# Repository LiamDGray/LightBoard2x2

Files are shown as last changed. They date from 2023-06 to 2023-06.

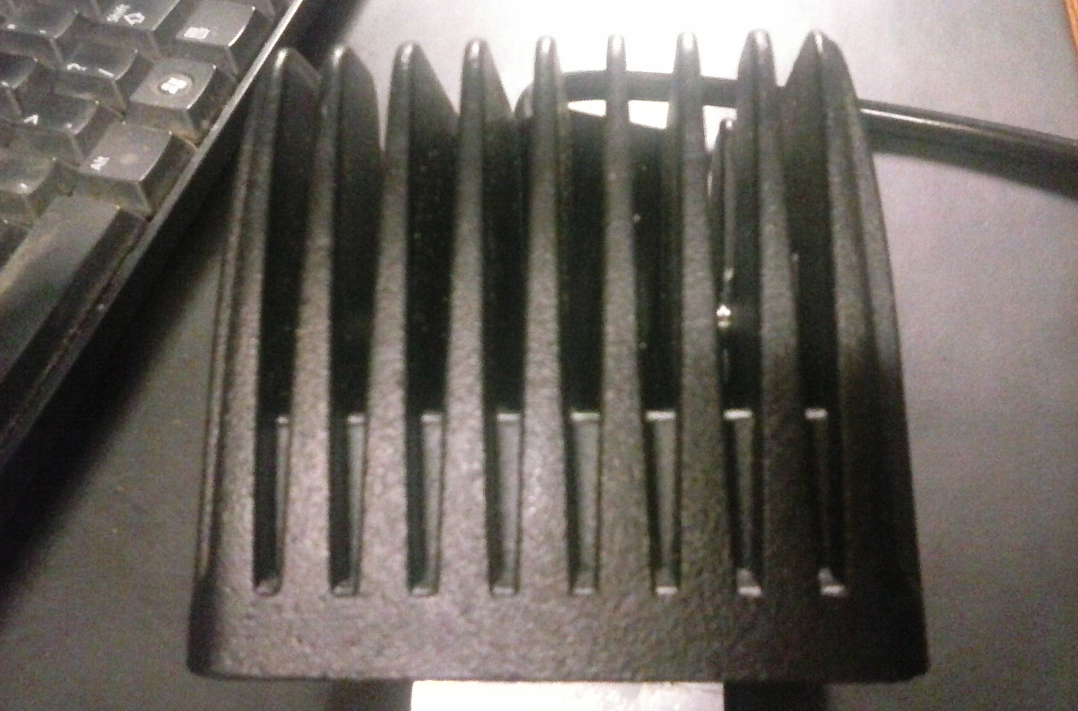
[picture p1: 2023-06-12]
Photos of Chinese product/Chinese 2x2 housing top.jpg

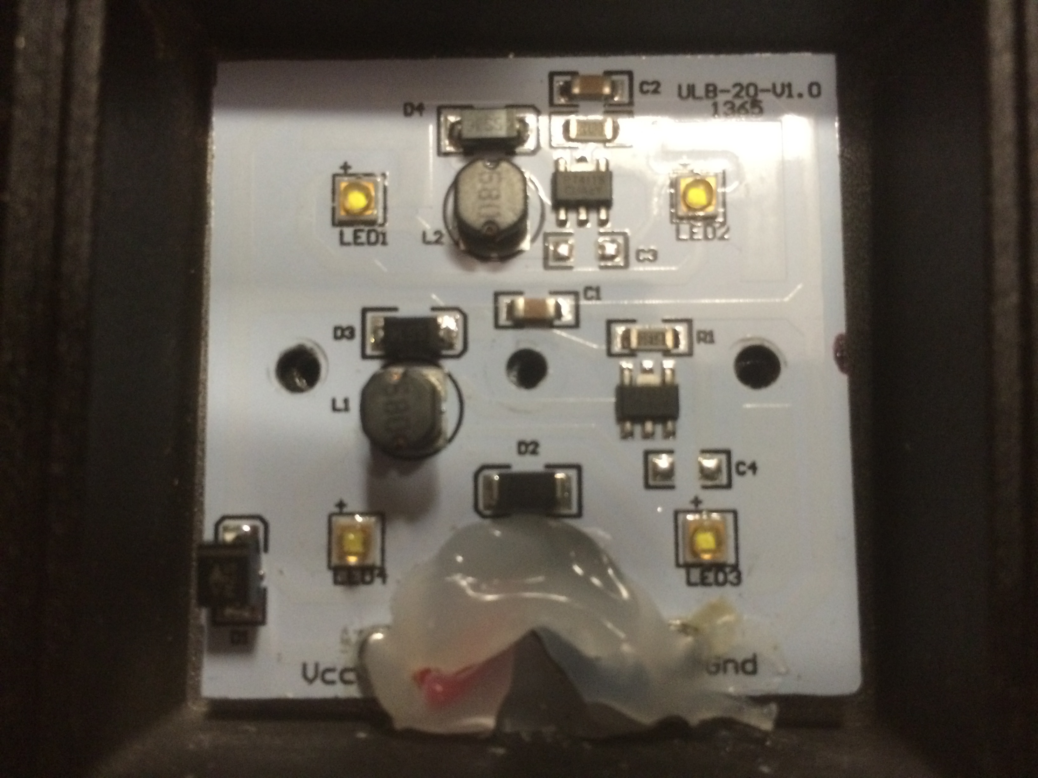
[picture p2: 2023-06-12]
Photos of Chinese product/Chinese 2x2_ board.JPG

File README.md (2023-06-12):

High-power 2x2 LED board based on PicoBuck LED Driver
===================

### Repository Contents
-------------------
- Design notes.docx
- Eagle CAD source files/
- LICENSE.md
- Light bar schematic.pdf
- Mechanical_drawing_of_board_for_subs.pdf
- Photos of Chinese product/
- Quotes/
- README.md (this file)
- Requirements traceability matrix.xlsx
- Simulations _ spreadsheets/
- Specifications for board fab _ assembly/
- Test results/

### License Information
-------------------
- The hardware is released under [Creative Commons Attribution-ShareAlike 3.0 Unported (CC BY-SA 3.0)](http://creativecommons.org/licenses/by-sa/3.0/).  Please feel free to do anything you want with it; just keep this license attached.

### Additional Information
----------------------
- My starting point was the [SparkFun PicoBuck](https://github.com/sparkfun/PicoBuck) LED driver, which was a collaboration with Ethan Zonca and also licensed under CC BY-SA 3.0.
- I used Eagle CAD 7.2.0 (a version current in early 2015).
- I added thermal foldback and dimming.
- I designed this board in 2015 at the request of [Traxda, LLC](https://www.traxda.com/) in Tucson, Arizona, USA. Traxda was kind enough to accept the work product under this same license (CC BY-SA 3.0).
- This was my first LED board, my first constant-current power supply, my first use of thermal foldback, my first dimming LED driver, and my first PCB. Back in 2015, I fabricated multiple iterations of the board and did basic functional testing, but I was unable to find a subcontractor with the equipment to test for electromagnetic compatibility (EMC) or otherwise review my design. My client, Traxda, opted not to have me finish, and I moved on to other things.
- In 2023, I am thinking of adapting the design for something related to LiFi and OpenVLC.
- If you have any suggestions, please open an issue or, better yet, make a pull request!
- You're welcome to sponsor my work through [Github Sponsors](https://github.com/sponsors/LiamDGray/).

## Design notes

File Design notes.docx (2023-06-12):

# Design Notes for v.1

(a 2x2” board to replace the Chinese board in a 3x3” light)

# Component selection

We have designed the present board to meet the first requirement: a drop-in warranty replacement board for the Chinese lights currently being advertised as having “four 5W LEDs.” However, it is unlikely that the LEDs in the Chinese board really are 5W LEDs. They seem to be 3W LEDs, for a few reasons:

5W LEDs currently available through US distributors (1) are quite expensive (starting at $4.91 apiece at quantity 2500 at DigiKey) and (2) require higher voltages (around 6 or 7 volts) than the 2.9 volts apiece of the 3W LEDs used in the present design. (3) Known 5W LEDs also are larger (e.g. 5.7mm diameter) than the LEDs in the Chinese board (2mm diameter) and would not fit within the apertures of the reflectors designed for this board.

Philips Luxeon Rebel LEDs were selected for their small size, high lumens per watt, low price, and plentiful availability in quantities sufficient for production runs of 1000 boards. In fact, all components were chosen for their availability; any components with limited distributor inventory were replaced with more-plentiful substitutes. (For production quantity, DigiKey, Mouser, Avnet, and CM’s preferred vendors should be checked for best prices.)

Automotive compliant (AEQ rated) components were selected whenever possible. And, as a voltage reference, the 5.6V Zener diode was selected for its relatively good temperature stability versus Zener diodes of higher and lower voltages.

References:

http://www.digikey.com/product-search/en/optoelectronics/led-lighting-white/525606?stock=1

http://www.aecouncil.com/AECDocuments.html

# Schematic

The present design, v.1, is a derivative of PicoBuck, which was designed by Ethan Zonca. Specifically, it follows two of PicoBuck’s three parallel buck driver circuits.

Each of the two parallel buck drivers drives a series of two 3-watt (2.9 volt) LEDs with a nominal 680mA current. This level of current approximates the current at which the LEDs’ manufacturer measured their performance. Optionally, switching the values of resistors R1A and R1B to 0.10 Ohm would result in the LEDs being driven with current of up to 972mA (43% greater) and emitting brighter light, subject to thermal foldback. Since the thermal foldback feature (see below) limits average current in order to keep temperature below 85 degrees Celsius, the higher-valued resistors may or may not increase brightness.

In addition, a subcircuit on the input improves electromagnetic compatibility in the automotive environment.

The schematic was developed in Cadsoft Eagle. It (with extension .sch) and the board layout (with extension .brd) were last edited with version 7.2 (freeware edition) and are stored in the folder “Eagle CAD source files.”

# Simulation

Simulation was done in Zetex Circuit Simulator, which is available free of charge as a download from Diodes Inc, maker of the driver chip used in this design. The simulation file is stored as “v.1.sxsch.” Dimmer circuit calculations were done in a Google Sheets spreadsheet called “Dimmer circuit calculations.” Both are stored in the folder “Simulations and Spreadsheets” in the project’s Google Drive folder.

# Layout

The printed circuit board (PCB) was laid out almost entirely in large planes (broad rectangular areas), rather than in thin traces, to minimize inductance and interference with nearby electronic devices. To minimize inductive loops:

- C1 was placed very close to the driver’s Vin pin
- R1 was placed very close to the driver’s pins Vin and SET
- D1’s anode and the inductor were placed very close to the driver’s SW pin

The broad planes also prove durable, resist tearing, during rework. However, the pads are without thermal relief. (For this reason, oven reflow is recommended.)

The board has holes in the same pattern as in the original board, but the center hole has been enlarged (as per the drawing provided by Company) to match the size of the other two.

# Thermal considerations

To dissipate heat efficiently, to maximize the life of LEDs and other components on the board, the Philips Luxeon Rebel datasheet was followed. This specified the number, size, and placement of plated through-holes (copper-lined holes connecting board’s top and bottom layers), as thermal vias, around each LED. These thermal vias conduct heat into the ground plane, the bottom layer of the board. This is bare metal (not covered by an insulating solder mask) and interfaces via a thermally conductive pad (made from Bergquist’s Sil-Pad K-4 material) to the heatsink/case of the light fixture. The datasheet also specified 1-ounce copper and 0.8mm FR-4 as the board material. This material, half the most common PCB thickness, offers less thermal resistance than the typical 1.6mm PCB. This board thickness, and the 12 mil minimum drill size, are not available at all board houses (PCB fabricators).

The board’s copper is coated in ENIG (electroless nickel immersion gold) to maximize thermal conductivity.

The thermal pad is optional, but in an automotive environment it is recommended. It is intended to prevent the gradual wearing off of the thin gold coating (ENIG) of the board’s bottom layer, due to friction against the heatsink/housing.

# Dimming

Dimming is via an external potentiometer, which shall be connected via a twisted wire pair exiting the assembly via the same cable that includes the power and ground pair. At full counter-clockwise rotation, the potentiometer’s resistance should be near zero and should result in lights being very dim or turning off. Turned full clockwise, its resistance should be around 500kOhms (+/- 20%; each of the two samples encountered during prototyping measured 400kOhms) and should result in the lights reaching maximum brightness.

The mounting of the external potentiometer is TBD but could include mounting through a hole in an existing panel of the vehicle or in a small enclosure which mounts flush to some surface of the vehicle’s cab.

# Thermal Foldback

Additional dimming to prevent overheating of the LEDs is achieved through the use of a negative temperature coefficient thermistor placed near the bottom right LED. As LEDs heat up slightly, so will this thermistor, whose resistance decreases, which reduces the voltage at the drivers’ CTRL pins, which reduces the current through the LEDs, which cools them slightly. The circuit was calibrated to let the thermistor stay just shy of 85 degrees Celsius, the temperature at which the LEDs’ performance was measured and specified.

# EMC: electromagnetic compatibility

The board was designed to reduce electromagnetic emissions (make it act less like a radio transmitter) and to resist damage from it and other components being connected or disconnected, or from transient spikes in voltage. Toward this end, the following references were consulted and synthesized:

“AL8805 MR16 EMC guide” downloaded from:

http://www.digikey.com/videos/en/v/AL8805-MR16-EMC-guide/2195801950001

“AN57: Automotive EMC considerations for switching regulator LED lighting applications using ZXLD1362” downloaded from:

http://www.diodes.com/_files/products_appnote_pdfs/zetex/an57.pdf

“AL8805 Calculator” downloaded from:

http://www.diodes.com/calculators.html

“Design an L-C Low pass or High pass Filter (V 1.1 May 18, 2008)” at:

http://www.wa4dsy.net/filter/hp_lp_filter.html

AN57 provided an example for the input subcircuit, which includes a load dump and battery reverse protection and an input “Pi” filter tuned to prevent the switching frequency of the drivers from being injected into the power supply. The switching frequency was calculated by the AL8805 Calculator, an Excel spreadsheet provided by Diodes Inc.. Together, these circuit elements protect the board and surrounding electronics from conducted electromagnetic emissions and from other events that can occur the automotive environment and could damage circuits.

# PCB fabrication

Given the particularly small minimum drill size and the 0.8mm FR-4 material, not all board houses can produce this design. To find a suitable US-based board house, the document “Light bar fab notes.pdf” should be sent with any request for quotation. This will enable the board house to determine whether they can meet the requirements. (Note: The Contract Manufacturer [CM] retained to assemble the board could select the board house to produce the PCBs.)

# PCB assembly

Assembly considerations include vibration resistance, European regulatory compliance (TBD) and cable (TBD).

The inductor L1 should be epoxied to the board for vibration resistance. So too, whoever attaches the cable should epoxy the ends of each wire near their solder joints to the board.

The board should be assembled with lead-free solder if (TBD, depending on the cost of this option) Company decides product is to meet European requirements after January 1, 2016. After that date, the European “ELV” (End of Life Vehicle) exemption 8a, permitting leaded solder, may expire.

If lead-free solder is used, the board should be conformally coated with 2-mil “Arathane” (urethane) to prevent the growth of tin “whiskers.” This has been reported to work for 11 years, at least.

An approximately one-foot length of cable should be cut, stripped, tinned, and soldered to (four pads on) each board, either by the board assembler or in-house (TBD, depending on cost). This cable is specified in the document “Cable Specification” in the folder “Specifications for board fab and assembly.”

# Mechanical assembly

This shall be done in-house. As in the Chinese original,

1. A water resistant grommet providing strain relief should fit snugly around the cable where it exits the assembly.
2. Silicone should be used to fill and seal the hole around the cable on the board side.

# Future design for increased brightness

One engineer described the present housing and heatsink as “overbuilt” for the circuit board and LEDs it contains, and given summer warehouse temperature measurements, likely the housing really can dissipate 20W or more.

For a future design with 5W (or greater) LEDs, to create the higher voltage required, one would replace the two “buck” drivers with a single “buck-boost” driver. A buck-boost design can drive a series of LEDs whose total voltage exceeds that of the input power supply. Thus from, for example, a 12V supply, even with 10% loss, resulting in 10.8V available, one could drive LED series totalling 12V, 20V, or even more.

This might require substituting the reflector assembly also, for reflectors with a larger aperture. A hack during prototyping might be to drill out the apertures in the current reflectors.

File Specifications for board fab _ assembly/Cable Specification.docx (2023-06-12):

# Cable Specification

# Requirements

1. Cable's total length (end to end) is about 12 inches (tolerance +/- 0.5 inch)
2. 2. A flexible rubber or plastic grommet for strain relief and water resistance shall fit snugly around cable and shall fit into a hole whose diameter is 10.4mm +/- 0.1mm.
3. Cable, preferably shielded, shall contain two twisted pairs of #18 to #22 stranded copper wire.
4. Cable's jacket shall be stripped 1 inch (+/- 0.25” ) back from each end of cable.
5. Each of the four wires' insulation shall be stripped 0.25” (+/- 0.125”) back from each end and shall be tinned at each end.
6. One pair of wires shall be soldered to VCC and GND (red and black, respectively, if available).
7. One end of the other pair (for example, white and green) shall be soldered to DIM1 and DIM2. This pair’s other end shall be soldered to the potentiometer’s wiper (terminal 2, center terminal) and to the left terminal, such that a clockwise turn increases resistance between these two connected terminals. (The two wires could be reversed with no consequence; order is not important. The potentiometer is used as a variable resistor, with its third terminal floating.)
8. The wires shall be epoxied to the board near the solder joints.
9. Preferably the jacket is UV-resistant.

# Examples

One or more of the following cable stock, sold by the foot, may meet the requirements, if a suitable grommet can be found:

- 2 twisted pair 20 AWG shielded, $1.88 per foot: http://www.digikey.com/product-search/en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
- 3 pair 22 AWG shielded -- could combine two pair for power? $2.59 per foot: http://www.digikey.com/product-detail/en/25483%20BK005/25483%20BK005-ND/5120450
- 2 twisted pair 22 AWG shielded, $0.83 to $0.43 per foot: http://www.altex.com/Belden-22AWG-2-Pair-Shielded-Twisted-Pair-Cable-8723-BEL-P140284.aspx

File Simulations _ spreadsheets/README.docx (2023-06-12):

README

Simulations in this folder are for Zetex Circuit Simulator, which can be

downloaded from Diodes Inc at:

http://www.diodes.com/simulators.html

As of April 2, 2015, the last version run was version 5.40b, on Windows 8.

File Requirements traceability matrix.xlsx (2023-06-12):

Category | Requirement | Notes | BOM (https://drive.google.com/#folders/0B2ThqQRnzscgajMyOXN3WFJqMWc) | Schematic | Simulation | Layout | Prototype
Luminous flux or luminous power | At low temperatures (max intensity), within 10% of that of the model board (TBD, probably about 220 lumens per LED emitter) | TBD (will specify after we measure the model using an integrating sphere) | Luxeon Rebel ES emitters | LED1A,LED2A,LED1B,LED2B
Emitters' viewing angle | TBD | TBD (will specify after we measure the model's emitters) http://www.barco.com/~/media/Downloads/White%20papers/2014/WhitePaper%20Viewing%20Angle_final%20pdf.pdf and http://www.candlepowerforums.com/vb/showthread.php
Power consumption (Watts) | Chinese board draws 13.2W +/- 1W | The model board draws 1.1A at 12V (about 1.1A per 6V parallel branch) | parts sized to carry 2A or 1A current, plus tolerance | If R1A and R1B are set to permit 680mA current through each 5.8V series of LEDs, the board should draw around 7.9W. At 12V that would be about 0.66A. If current is 972mA, the board should draw up to (0.66A * 972 / 680), or 0.94A, subject to thermal foldback.
Thermal tolerance | At least 50C ambient (see notes, right) or preferably 70C | At least 50C, though parts are rated at or below 85 degC. Thermal foldback circuit calibrated to keep below 85 degC. |  | RNTC1, R4 | N/A
 | Meet specs by LED emitter manufacturer (e.g. Philips) | www.cree.com/xlamp_app_notes/thermal_management and www.cree.com/xlamp_app_notes/pcb_thermal Use Aluminum board or 0.8mm FR-4, which is much easer to find in 2 layers and will suffice due to thermal foldback. In summer, model board only reached 115 degF in warehouse in Tucson. |  | see net "TH" | N/A | Thermal vias around each emitter
 |  | In summer, model board only reached 115 degF (about 46 degF) in warehouse in Tucson.
Color temperature ("cool white" vs "warm white") | About 5000K | Match model board's emitters (specific color temp TBD)
Electro-magnetic compatibility (EMC) | Emissions not worse than emission spectrum from "Diodes [Zetex] Circuit Simulator" (or other free SPICE implementation) transient simulation of model circuit, to be posted shortly. | Probably not crucial for aftermarket automotive accessories. Stretch goal could be to meet specs below by following principles as in http://diodes.com/_files/products_appnote_pdfs/zetex/an57.pdf and http://diodes.com/_files/simulator/AN57_1362_emc_compliant_at_350mA.sxsch |  | C5,L2,C1
 |  | CISPR-25: Conducted and radiated emissions (Europe and Worldwide standards)
 |  | ISO11452: Radiated immunity (North America and Worldwide standards)
 |  | 95/54/EC: Radiated emissions (European standards)
 |  | May prefer hysteretic controller (varying frequency) for EMI reduction (e.g. the PT4115 in the model board)
 |  | May use Pi filter (C,L,C) | C5,L2,C1 | C5,L2,C1
 |  | Use twisted pair for power/ground and dim
Mechanical | Board shall fit 47mm square contour (X,Y = 47mm x 47mm) | See photos in folder https://drive.google.com/folderview?id=0B2ThqQRnzscgajMyOXN3WFJqMWc&usp=drive_web
 | Shall have holes placed and sized to fit the two board-mounting screws and one (central) reflector-mounting screw (measurements below)
 | Emitter shall fit inside 5.2mm diameter aperture at reflector base | Diagonal of LED emitter must be < 5 mm
 | Rounded slot for wires to pass from rear side of board shall be 14.22mm-wide rounded slot of max depth 12.11mm from board edge.
 | Board thickness (Z): 1.6mm or less
 | left hole center to right hole center: 33.44 mm
 | left hole left to right hole right: 36.78mm
 | left hole center to center hole center: 16.45mm
 | left hole left to center hole right: 19.86mm
 | board edge to hole edge: 5.01mm
 | left & right hole diam: 3.21mm
 | center hole diam: 2.90mm
 | top left corner of model's 3x3mm emitter is 8.95mm from top left corner of board
 | Model LED X,Y: 3mm x 3mm
 | Model board+LED emitter thickness (Z): 3.57mm
 | Model LED's round part "bulb" 1.94mm diam.
 | LEDs' "bulb" round to "bulb" round, outside: 27.04mm
Supply voltage | +12V DC, 1.1A +/- 0.1A (solder pads on top of board)
Longevity | Reduce current when LEDs get hot, to prevent overheating | One term for this is "thermal foldback." Thermistor in voltage divider input to driver's CTRL (dimming) pin. | RNTC1 | RNTC1 | N/A
 | No harmful current spikes during turn-on | One term for this is "soft start."
Dimming | Control by potentiometer. Provide pads to connect this, which will be located at end of long twisted-pair cable. | Use analog dimming, but for example of integration of dimming with thermal feedback, see http://dkc1.digikey.com/us/en/tod/Diodes/ZXLD1350_NoAudio/ZXLD1350_NoAudio.html |  | DIM1 and DIM2 pads to attach potentiometer (suggest 500k)
Cost | <= $10/board assembled & shipped, in qty. 1000 | Components BOM <= $6 probably | $11194 per 1000, not including cable
Manufacturability | Meets specs of PCB fabricator (including Gerber files, NC drill file, fabrication drawing with component placement and description of acceptance test)
Sourcing | All parts in current production and available via US distributors in quantity; little risk of shortage when shipping 2000 units/month
Manufacturer location | US-based manufacturer recommended. | Even if board is made in China, we will contract with a US-based intermediary, subject to US law, who will assume the legal risk for quality.
Schedule | Hoped to be ready to ship during peak season, January 15 - April 15 | Next steps, with example durations:
 |  | PCB prototype fab & shipping
 |  | Prototype assembly (SMT soldering) and test
 |  | Production PCB fab, assembly, test (qty 100) including thermal pads and cable spool or 1-foot cables
 |  | Shipping to Customer
 |  | at least 14 days thermal (always on) and on-off cycle testing
 |  | Retail shipping
 |  | TBD = "To Be Determined"

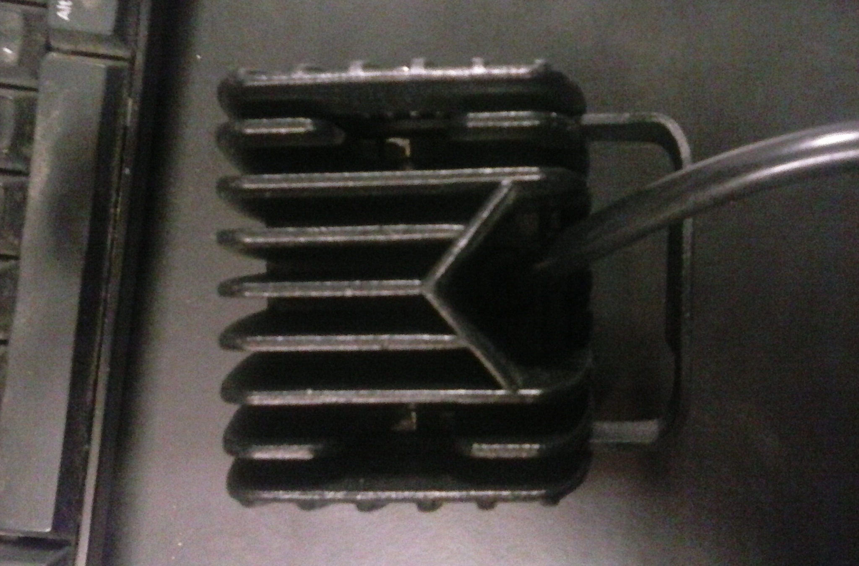
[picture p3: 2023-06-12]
Photos of Chinese product/Chinese 2x2 housing back.jpg

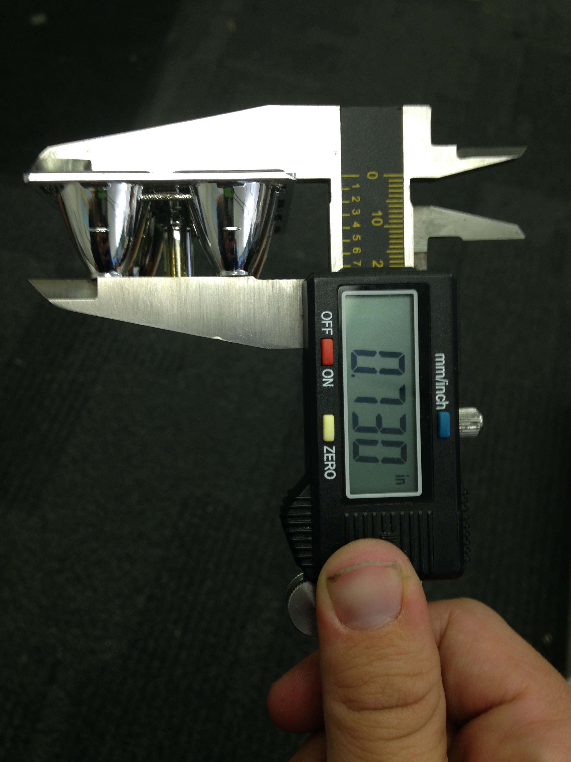
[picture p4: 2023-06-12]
Photos of Chinese product/Reflector Z.jpg

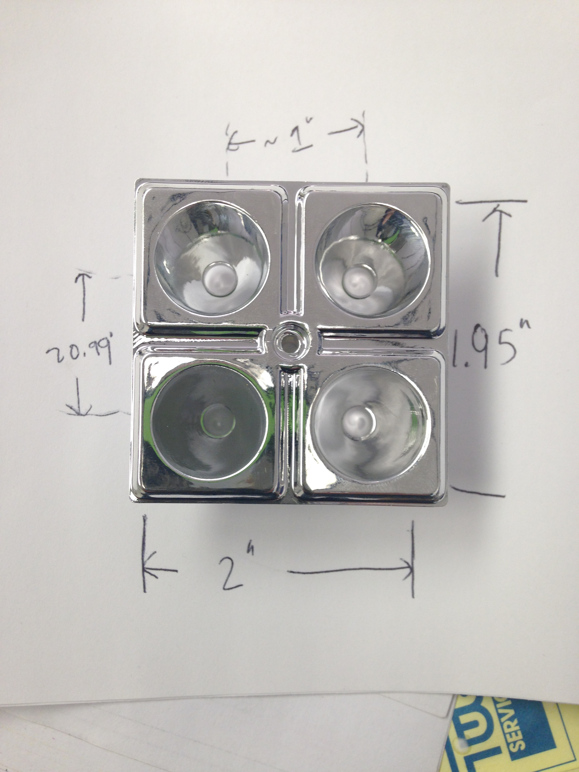
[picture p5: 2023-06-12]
Photos of Chinese product/Reflector X _ Y.JPG

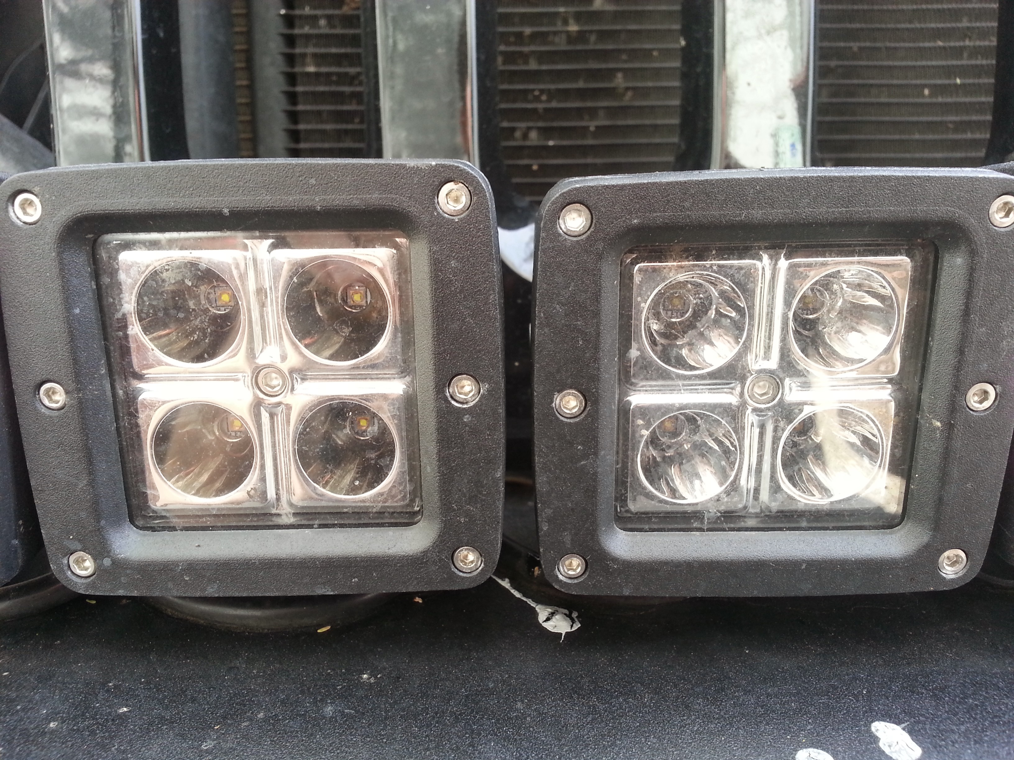
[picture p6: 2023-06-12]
Photos of Chinese product/Chinese 2x2_ in housing with reflectors.jpg

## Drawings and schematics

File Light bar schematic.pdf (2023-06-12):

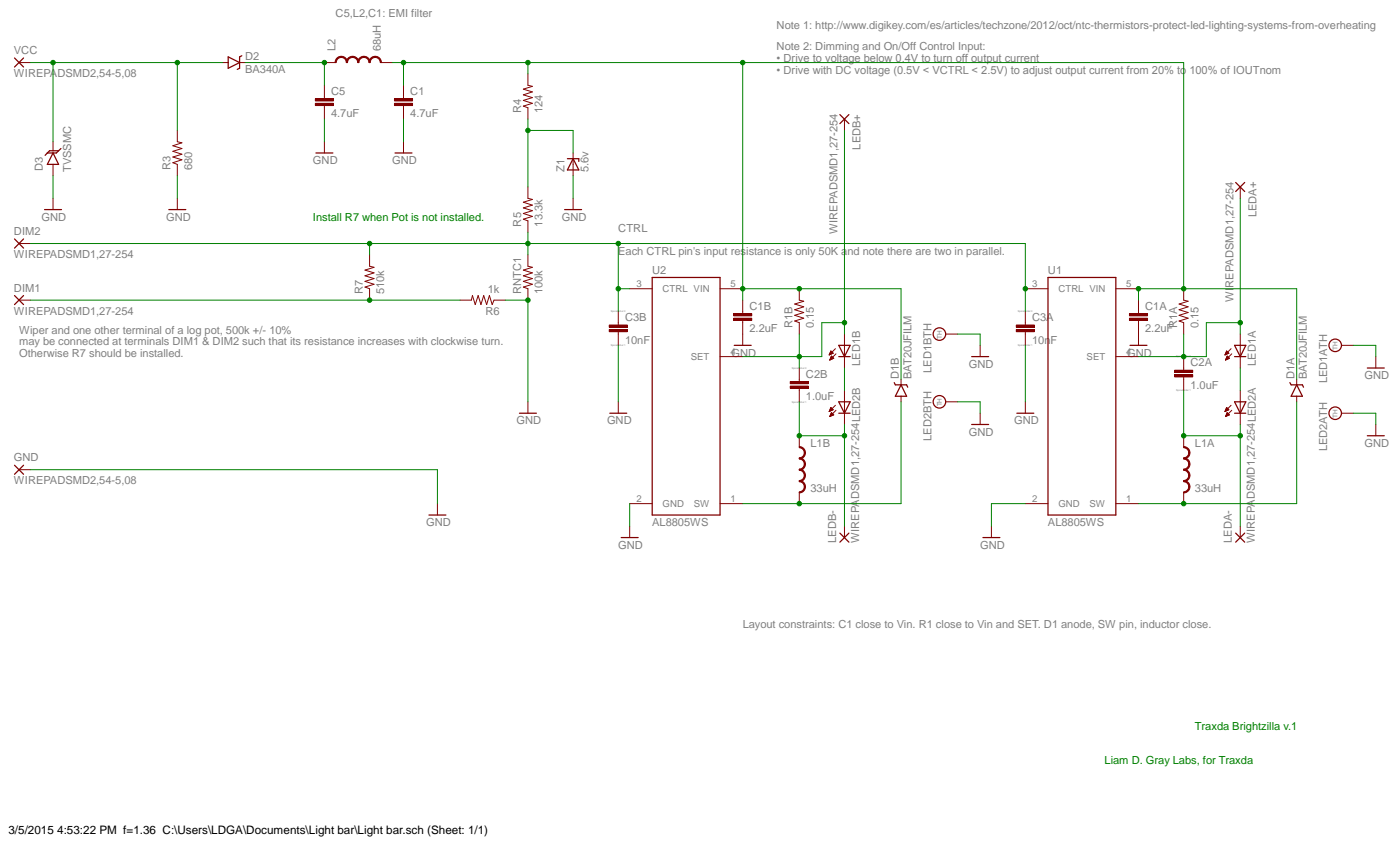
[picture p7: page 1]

Note 1: http://www.digikey.com/es/articles/techzone/2012/oct/ntc-thermistors-protect-led-lighting-systems-from-overheating
Note 2: Dimming and On/Off Control Input:
• Drive to voltage below 0.4V to turn off output current
• Drive with DC voltage (0.5V < VCTRL < 2.5V) to adjust output current from 20% to 100% of IOUTnom

Install R7 when Pot is not installed.

CTRL
Each CTRL pin's input resistance is only 50K and note there are two in parallel.

DIM1
WIREPADSMD1,27-254
Wiper and one other terminal of a log pot, 500k +/- 10%
may be connected at terminals DIM1 & DIM2 such that its resistance increases with clockwise turn.
Otherwise R7 should be installed.

Layout constraints: C1 close to Vin. R1 close to Vin and SET. D1 anode, SW pin, inductor close.

Liam D. Gray Labs, for Traxda

3/5/2015 4:53:22 PM f=1.36 C:\Users\LDGA\Documents\Light bar\Light bar.sch (Sheet: 1/1)

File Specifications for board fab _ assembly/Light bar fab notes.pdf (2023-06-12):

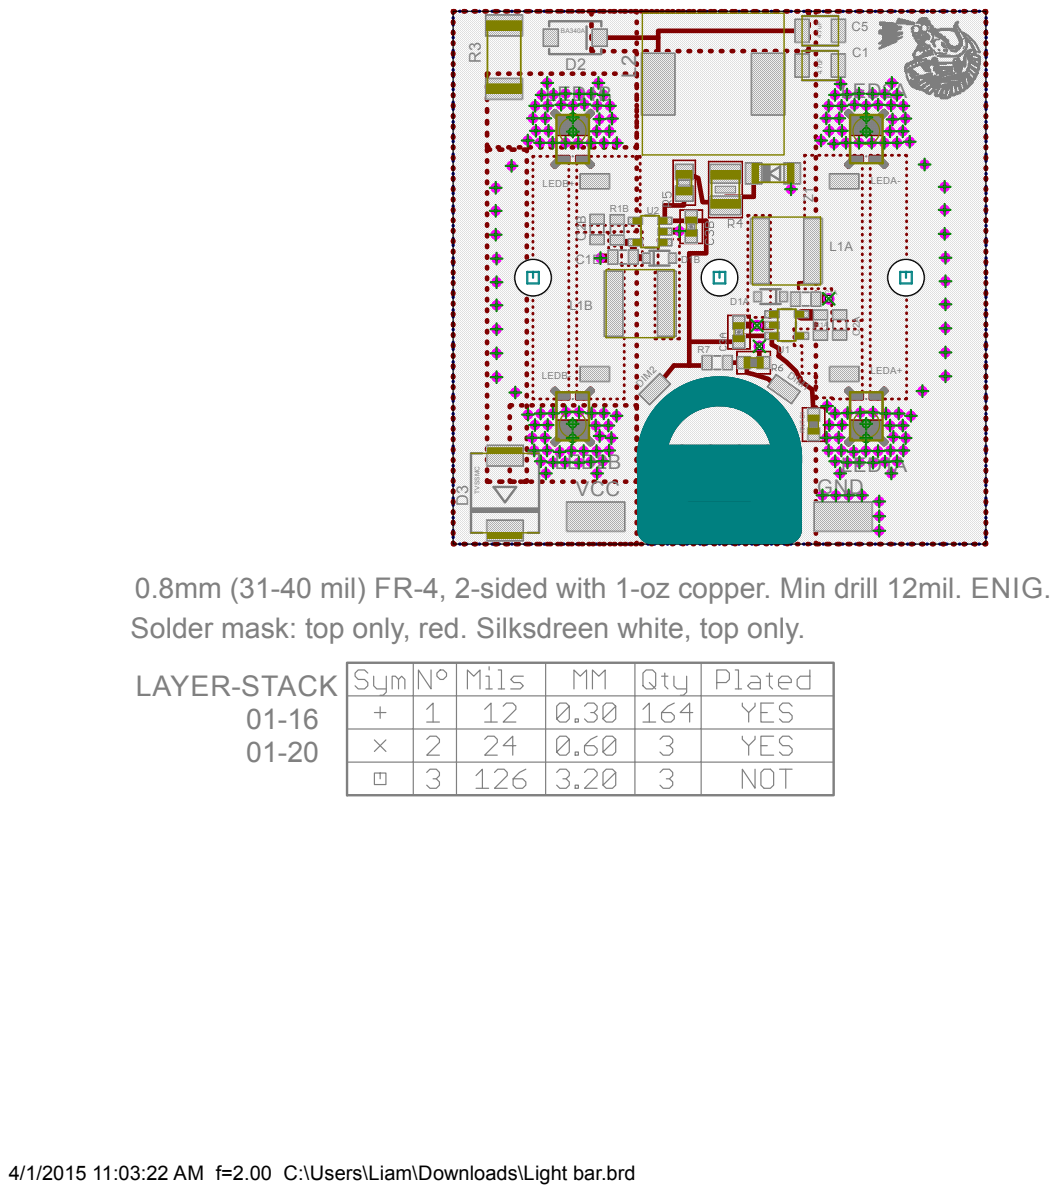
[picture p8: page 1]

0.8mm (31-40 mil) FR-4, 2-sided with 1-oz copper. Min drill 12mil. ENIG.
Solder mask: top only, red. Silksdreen white, top only.
LAYER-STACK

4/1/2015 11:03:22 AM f=2.00 C:\Users\Liam\Downloads\Light bar.brd

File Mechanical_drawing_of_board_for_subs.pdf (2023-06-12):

E

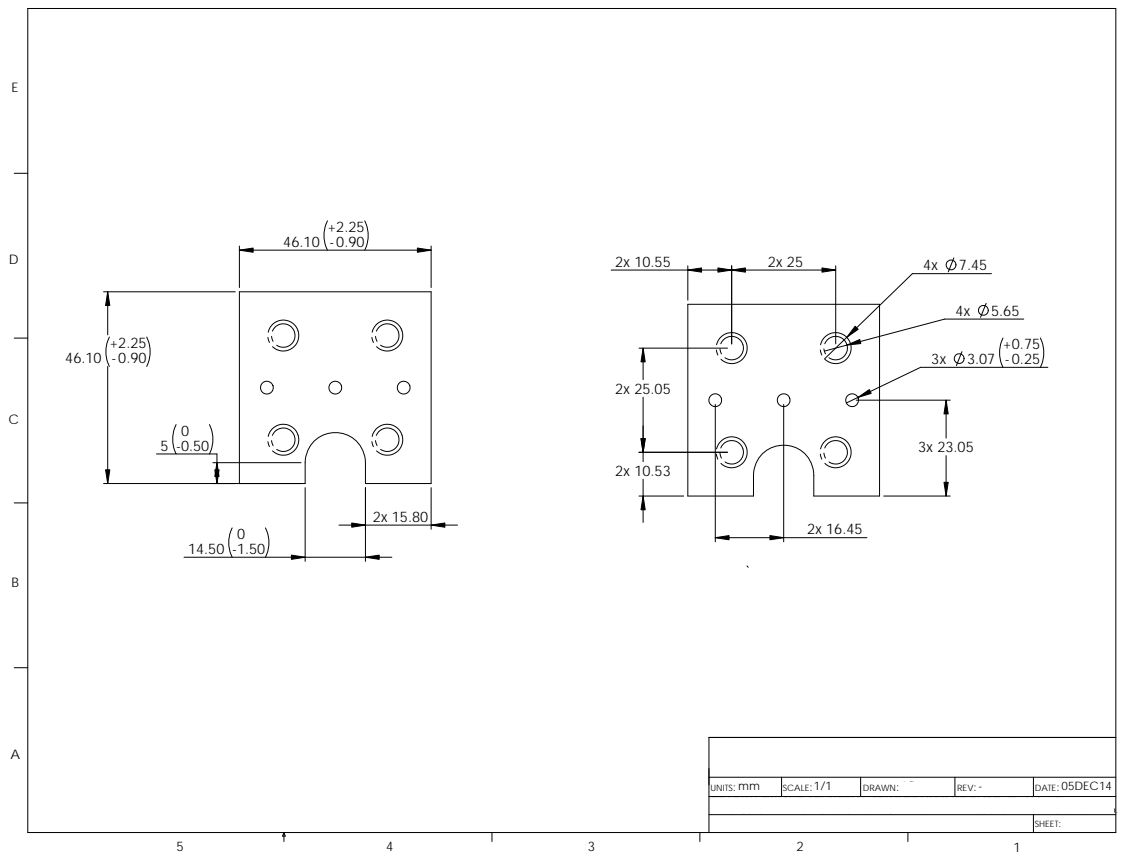
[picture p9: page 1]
UNITS:; SCALE:; DRAWN:; DATE:; TrAxDA LLC; REV:; SHEET; 05DEC14

4625 S. 3rd Ave. Tucson, AZ 85714 (888) 660-5892

THE INFORMATION CONTAINED IN THIS DRAWING IS THE SOLE PROPERTY OF TRAXDA LLC. ANY
REPRODUCTION IN PART OR AS A WHOLE WITHOUT THE WRITTEN PERMISSION OF TRAXDA LLC IS PROHIBITED.
Part Number:

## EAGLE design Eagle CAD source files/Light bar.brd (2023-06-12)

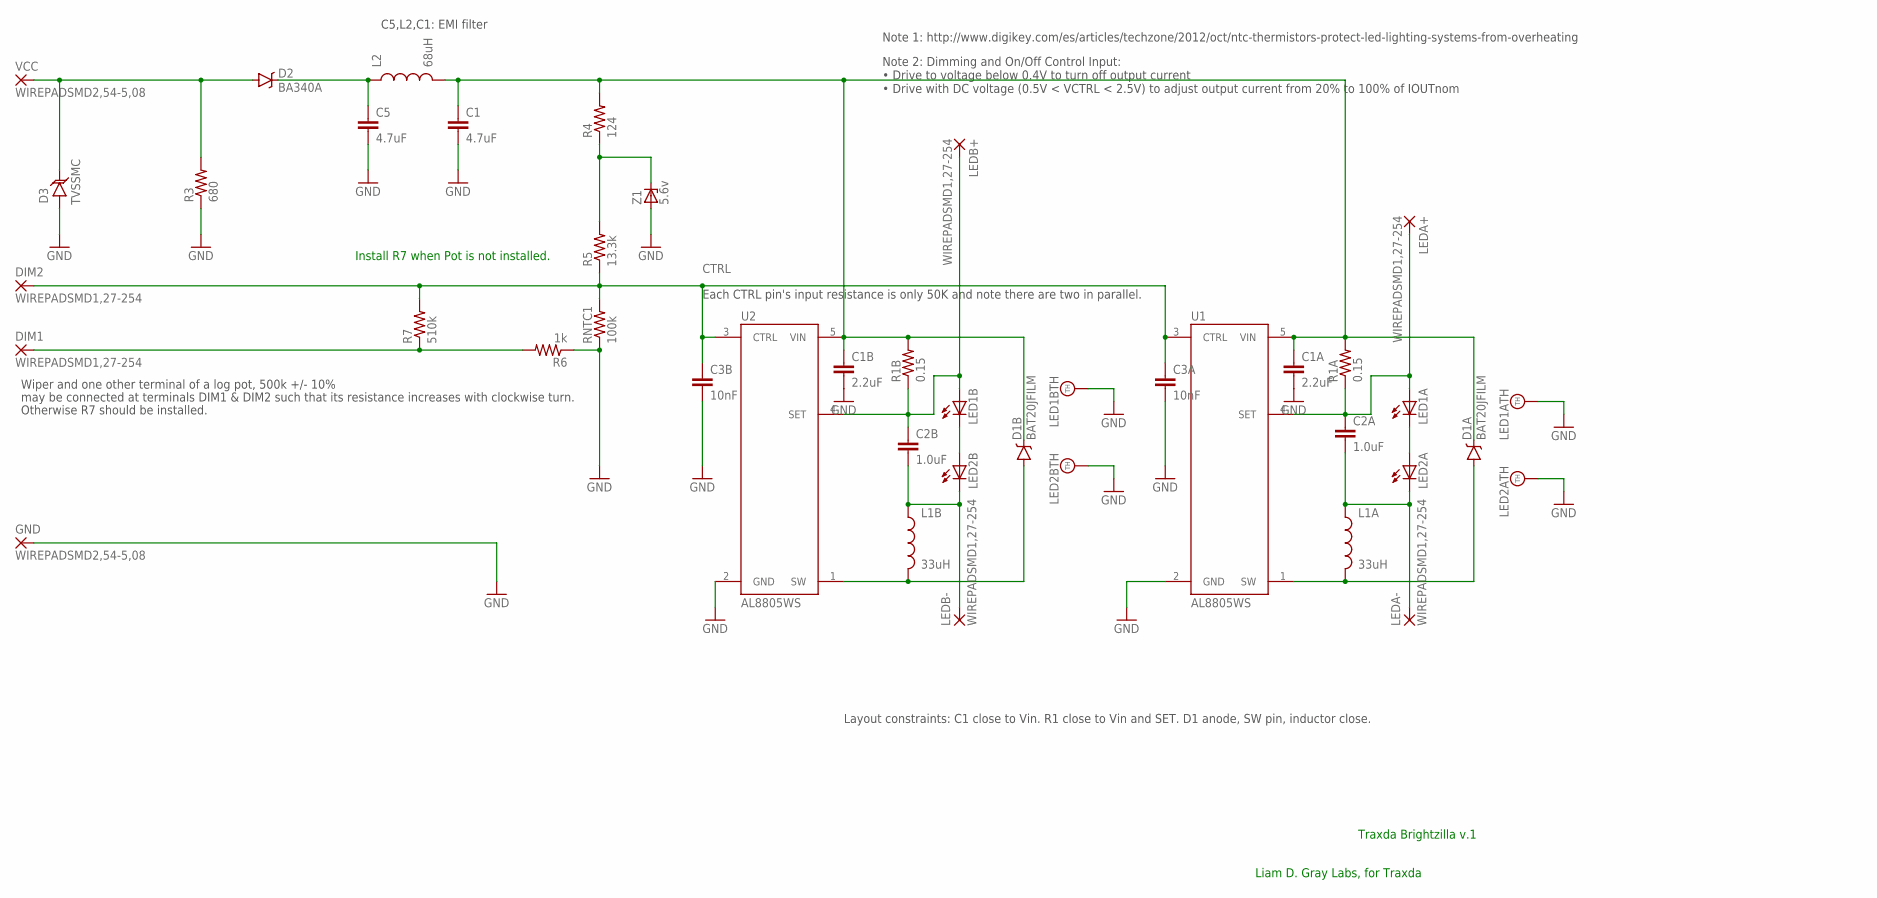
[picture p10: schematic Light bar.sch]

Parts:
C1, C5: 4.7uF; 1210
C1A, C1B: 2.2uF; 0805
C2A, C2B: 1.0uF; 0805
C3A, C3B: 10nF; 0603-CAP
D1A, D1B: BAT20JFILM; SOD-323
D2: BA340A; SMA-DIODE
D3: TVSSMC; SMC
DIM1, DIM2: WIREPADSMD1,27-254; SMD1,27-2,54
GND: WIREPADSMD2,54-5,08; SMD2,54-5,08
L1A, L1B: 33uH; NR6045
L2: 68uH; SRR1260
LED1A, LED1B, LED2A, LED2B: LUXEON_REBEL; LUXEON_REBEL_32MIL12MIL
LEDA+: WIREPADSMD1,27-254; SMD1,27-2,54
LEDA-: WIREPADSMD1,27-254; SMD1,27-2,54
LEDB+: WIREPADSMD1,27-254; SMD1,27-2,54
LEDB-: WIREPADSMD1,27-254; SMD1,27-2,54
R1A, R1B: 0.15; 0805
R3: 680; R2512
R4: 124; R1210
R5: 13.3k; R0805
R6: 1k; 0603-RES
R7: 510k; 0805
RNTC1: 100k; 0603-RES
U1, U2: AL8805WS; SOT23-5
VCC: WIREPADSMD2,54-5,08; SMD2,54-5,08
Z1: 5.6v; SOD80C

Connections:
CTRL: C3A.1, C3B.1, DIM2.1, R5.1, R7.2, RNTC1.2, U1.3 (CTRL), U2.3 (CTRL)
GND: C1.2, C1A.2, C1B.2, C3A.2, C3B.2, C5.2, D3.A, GND.1, LED1A.TH, LED1A.TH@1 (TH), LED1A.TH@2 (TH), LED1A.TH@3 (TH), LED1A.TH@4 (TH), LED1B.TH, LED1B.TH@1 (TH), LED1B.TH@2 (TH), LED1B.TH@3 (TH), LED1B.TH@4 (TH), LED2A.TH, LED2A.TH@1 (TH), LED2A.TH@2 (TH), LED2A.TH@3 (TH), LED2A.TH@4 (TH), LED2B.TH, LED2B.TH@1 (TH), LED2B.TH@2 (TH), LED2B.TH@3 (TH), LED2B.TH@4 (TH), R3.1, R6.1, RNTC1.1, U1.2 (GND), U2.2 (GND), Z1.A
unnamed: DIM1.1, R6.2, R7.1
unnamed: R4.1, R5.2, Z1.C
unnamed: LED1B.C, LED1B.C@1 (C), LED2B.A, LED2B.A@1 (A)
unnamed: LED1A.C, LED1A.C@1 (C), LED2A.A, LED2A.A@1 (A)
unnamed: C5.1, D2.C, L2.1
unnamed: C2A.2, L1A.1, LED2A.C, LED2A.C@1 (C), LEDA-.1
unnamed: C2B.2, L1B.1, LED2B.C, LED2B.C@1 (C), LEDB-.1
SET1: C2A.1, LED1A.A, LED1A.A@1 (A), LEDA+.1, R1A.1, U1.4 (SET)
SET2: C2B.1, LED1B.A, LED1B.A@1 (A), LEDB+.1, R1B.1, U2.4 (SET)
SW1: D1A.A, L1A.2, U1.1 (SW)
SW2: D1B.A, L1B.2, U2.1 (SW)
VCC: D2.A, D3.C, R3.2, VCC.1
VIN: C1.1, C1A.1, C1B.1, D1A.C, D1B.C, L2.2, R1A.2, R1B.2, R4.2, U1.5 (VIN), U2.5 (VIN)

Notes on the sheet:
Liam D. Gray Labs, for Traxda
Traxda Brightzilla v.1
Note 1: http://www.digikey.com/es/articles/techzone/2012/oct/ntc-thermistors-protect-led-lighting-systems-from-overheating
Note 2: Dimming and On/Off Control Input: • Drive to voltage below 0.4V to turn off output current • Drive with DC voltage (0.5V < VCTRL < 2.5V) to adjust output current from 20% to 100% of IOUTnom
Each CTRL pin's input resistance is only 50K and note there are two in parallel.
Wiper and one other terminal of a log pot, 500k +/- 10%
Layout constraints: C1 close to Vin. R1 close to Vin and SET. D1 anode, SW pin, inductor close.
C5,L2,C1: EMI filter
may be connected at terminals DIM1 & DIM2 such that its resistance increases with clockwise turn.
Install R7 when Pot is not installed.
Otherwise R7 should be installed.

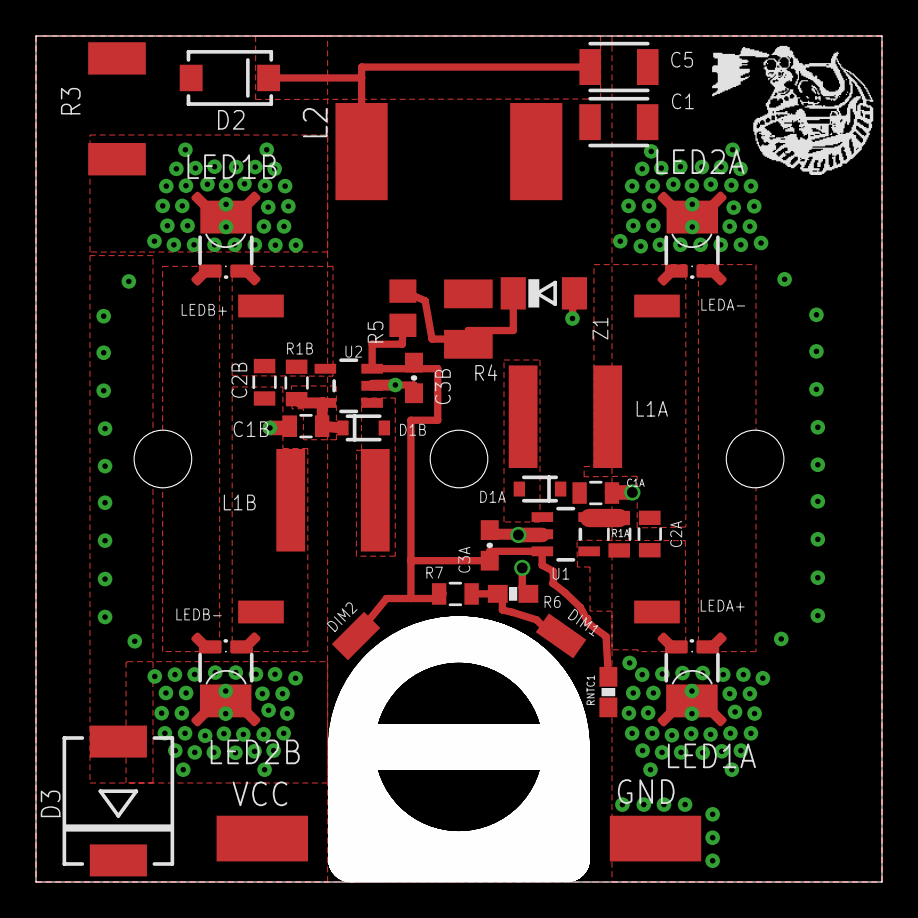
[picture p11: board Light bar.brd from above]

Board: 2 copper layers, 47.0 x 47.0 mm, 39 parts (0 on the bottom side), 15 nets.

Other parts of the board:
DRILEGEND: DRILEGEND

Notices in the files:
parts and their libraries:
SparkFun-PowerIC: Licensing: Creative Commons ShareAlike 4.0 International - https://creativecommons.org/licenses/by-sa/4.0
